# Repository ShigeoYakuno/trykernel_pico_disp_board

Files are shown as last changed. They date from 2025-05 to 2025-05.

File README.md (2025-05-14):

# trykernel_pico_disp_board

### 液晶のON/OFF回路
- MOSFETを使います
- 秋月で売っている30円のBSS138 Panjit製を使います
- Vthが1.5Vと使いやすいです
- 300mAしか引けませんが、液晶は100mA程度なので問題ないでしょう
- NチャネルのMOSFETです
- 


### MOSFETの基本回路通りに構成



- 基本回路どおりに設計します
- マイコン側に電流が流れる可能性があるので、直接受けず、抵抗を介します
- オープンドレイン接続を想定し、ゲートはプルダウンしておきます













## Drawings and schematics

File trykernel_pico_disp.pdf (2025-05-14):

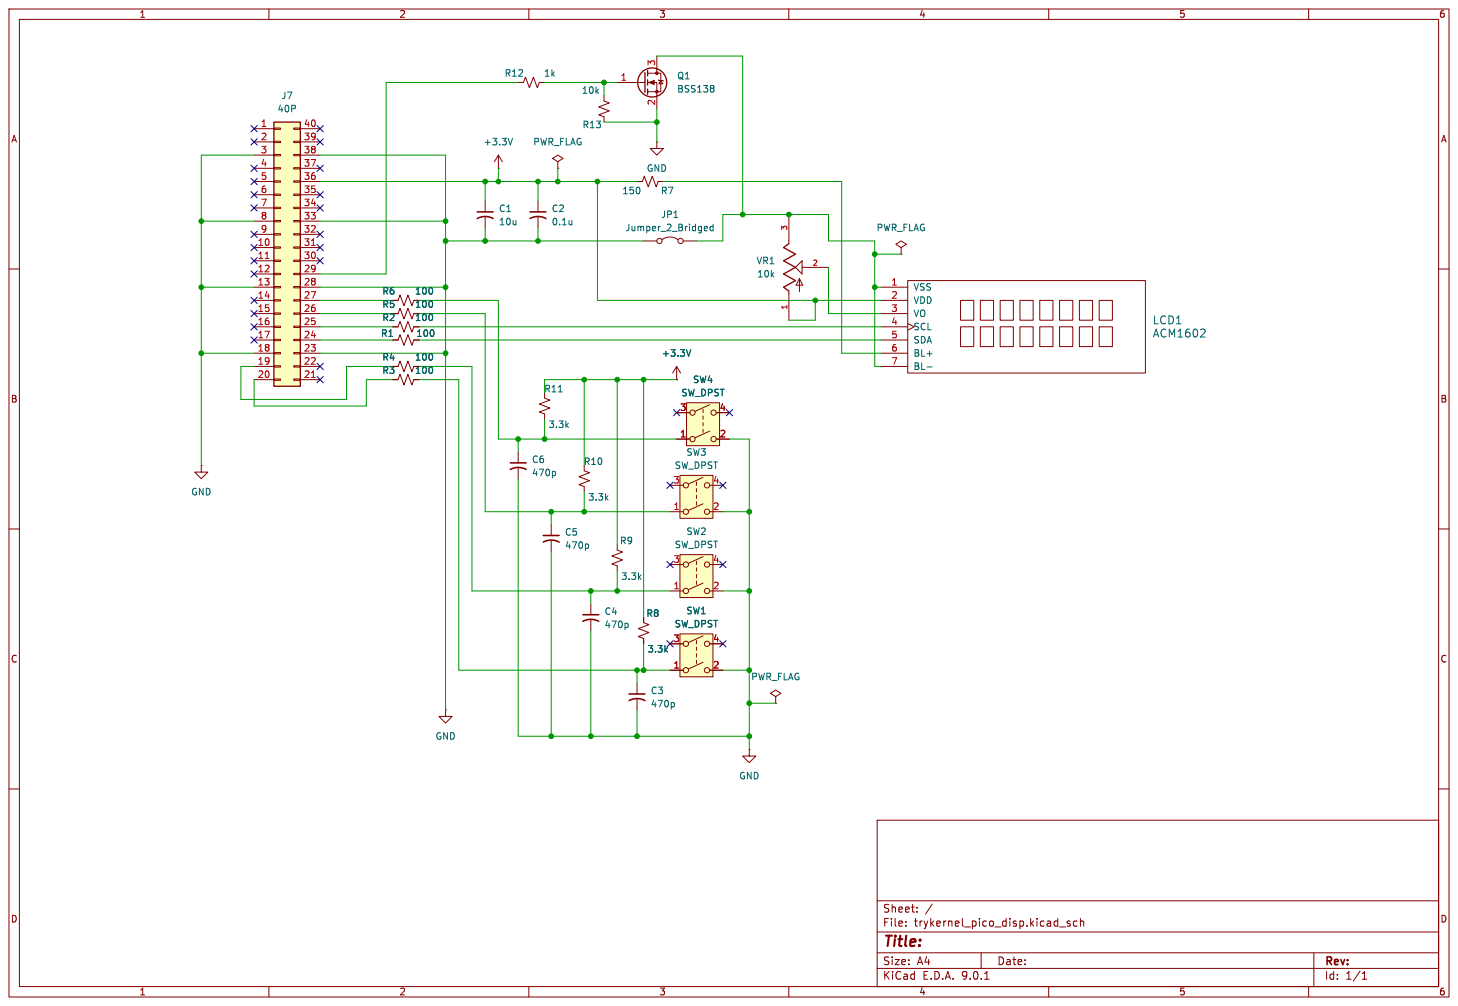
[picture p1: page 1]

Id: 1/1 Title: File: trykernel_pico_disp.kicad_sch Sheet: /

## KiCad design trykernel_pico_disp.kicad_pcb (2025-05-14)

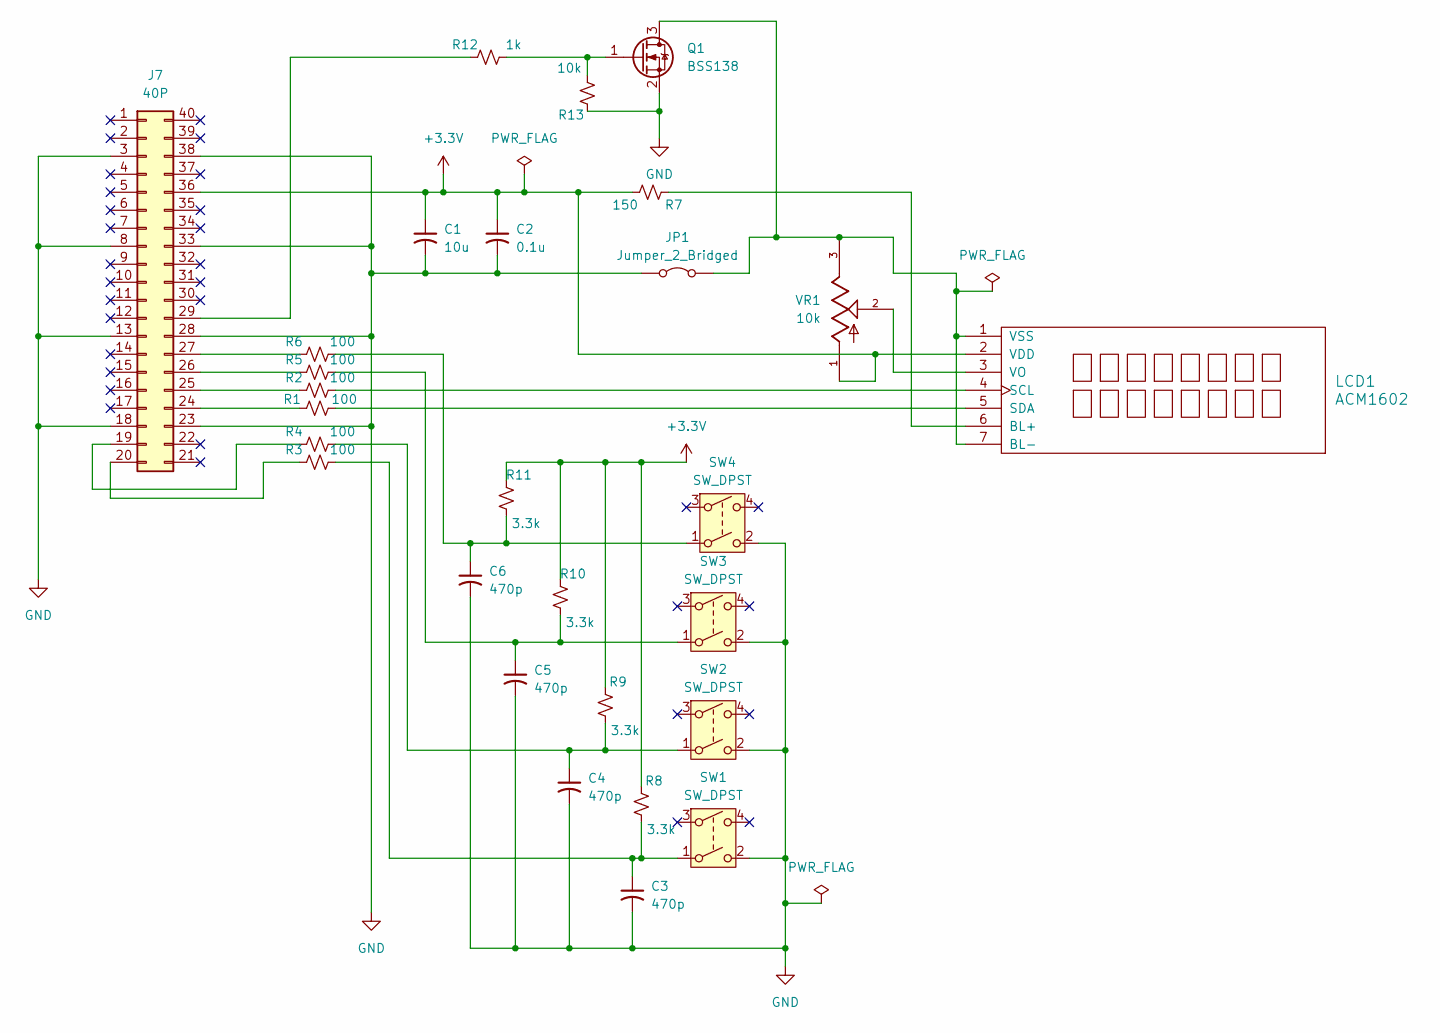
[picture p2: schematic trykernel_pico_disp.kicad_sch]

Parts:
C1: 10u; C_0603_1608Metric_Pad1.08x0.95mm_HandSolder
C2: 0.1u; C_0603_1608Metric_Pad1.08x0.95mm_HandSolder
C3, C4, C5, C6: 470p; C_0603_1608Metric_Pad1.08x0.95mm_HandSolder
J7: 40P; RPI_Hat_B+
JP1: Jumper_2_Bridged; PinHeader_1x02_P2.54mm_Vertical
LCD1: ACM1602; I2C_LCD-ACM1602NI-FLW-FBW-M01
Q1: BSS138; SOT-23
R1, R2, R3, R4, R5, R6: 100; R_0603_1608Metric_Pad0.98x0.95mm_HandSolder
R7: 150; R_0603_1608Metric_Pad0.98x0.95mm_HandSolder
R8, R9, R10, R11: 3.3k; R_0603_1608Metric_Pad0.98x0.95mm_HandSolder
R12: 1k; R_0603_1608Metric_Pad0.98x0.95mm_HandSolder
R13: 10k; R_0603_1608Metric_Pad0.98x0.95mm_HandSolder
SW1, SW2, SW3, SW4: SW_DPST; SW_TACT-EVQQ2Y03W
VR1: 10k; TRIM_3362P-1-103; PARTREV 08/26/10

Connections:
+3.3V: C1.1, C2.1, J7.36, LCD1.2 (VDD), R7.2, R8.1, R9.1, R10.1, R11.1, VR1.1
GND: C1.2, C2.2, C3.2, C4.2, C5.2, C6.2, J7.3, J7.8, J7.13, J7.18, J7.23, J7.28, J7.33, J7.38, JP1.1 (A), Q1.2 (S), R13.1, SW1.2, SW2.2, SW3.2, SW4.2
unnamed: C3.1, R3.2, R8.2, SW1.1
unnamed: C4.1, R4.2, R9.2, SW2.1
unnamed: C5.1, R5.2, R10.2, SW3.1
unnamed: C6.1, R6.2, R11.2, SW4.1
unnamed: J7.19, R4.1
unnamed: J7.20, R3.1
unnamed: J7.24, R1.1
unnamed: J7.25, R2.1
unnamed: J7.26, R5.1
unnamed: J7.27, R6.1
unnamed: J7.29, R12.1
unnamed: JP1.2 (B), LCD1.1 (VSS), LCD1.7 (BL-), Q1.3 (D), VR1.3
unnamed: LCD1.6 (BL+), R7.1
unnamed: LCD1.4 (SCL), R2.2
unnamed: LCD1.5 (SDA), R1.2
unnamed: LCD1.3 (VO), VR1.2
unnamed: Q1.1 (G), R12.2, R13.2

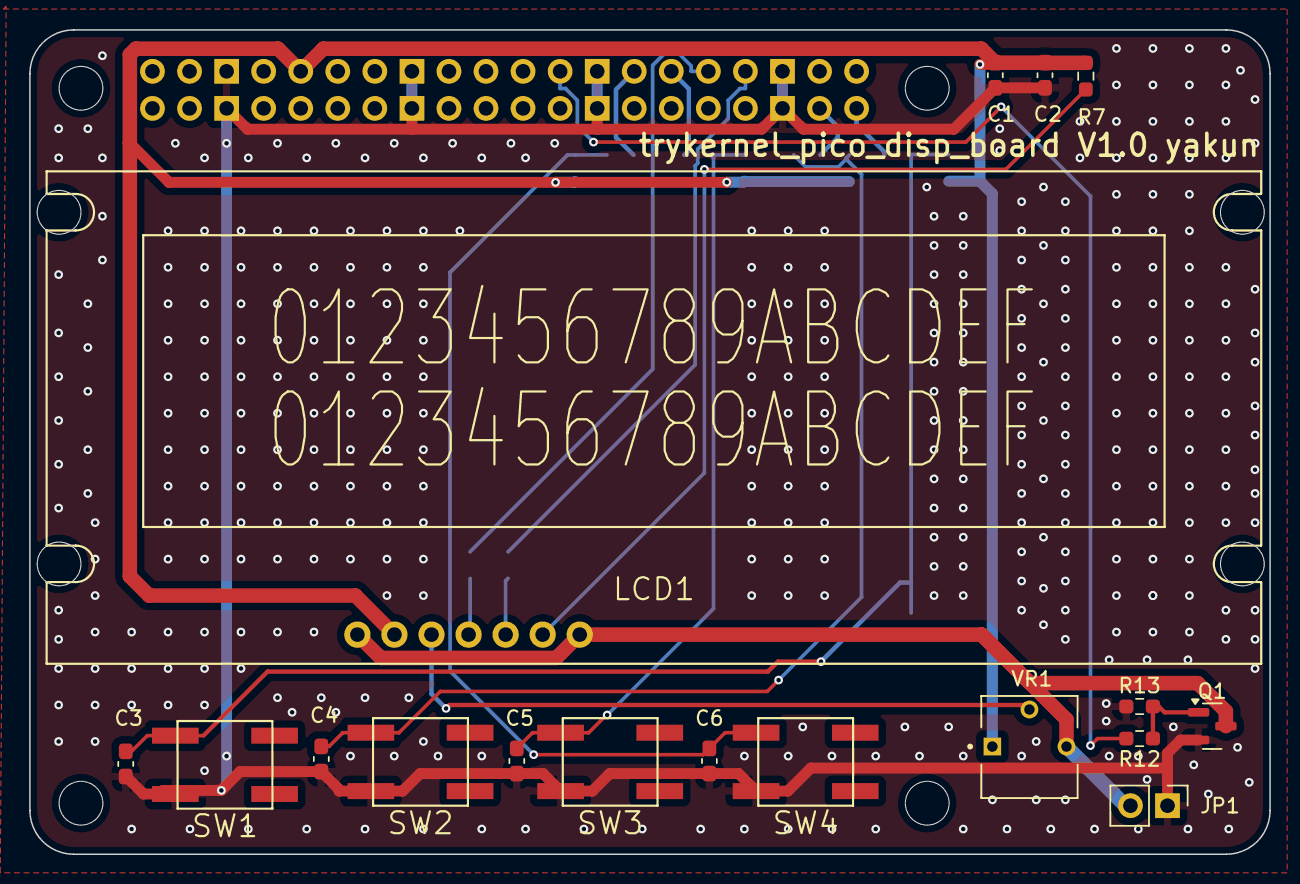
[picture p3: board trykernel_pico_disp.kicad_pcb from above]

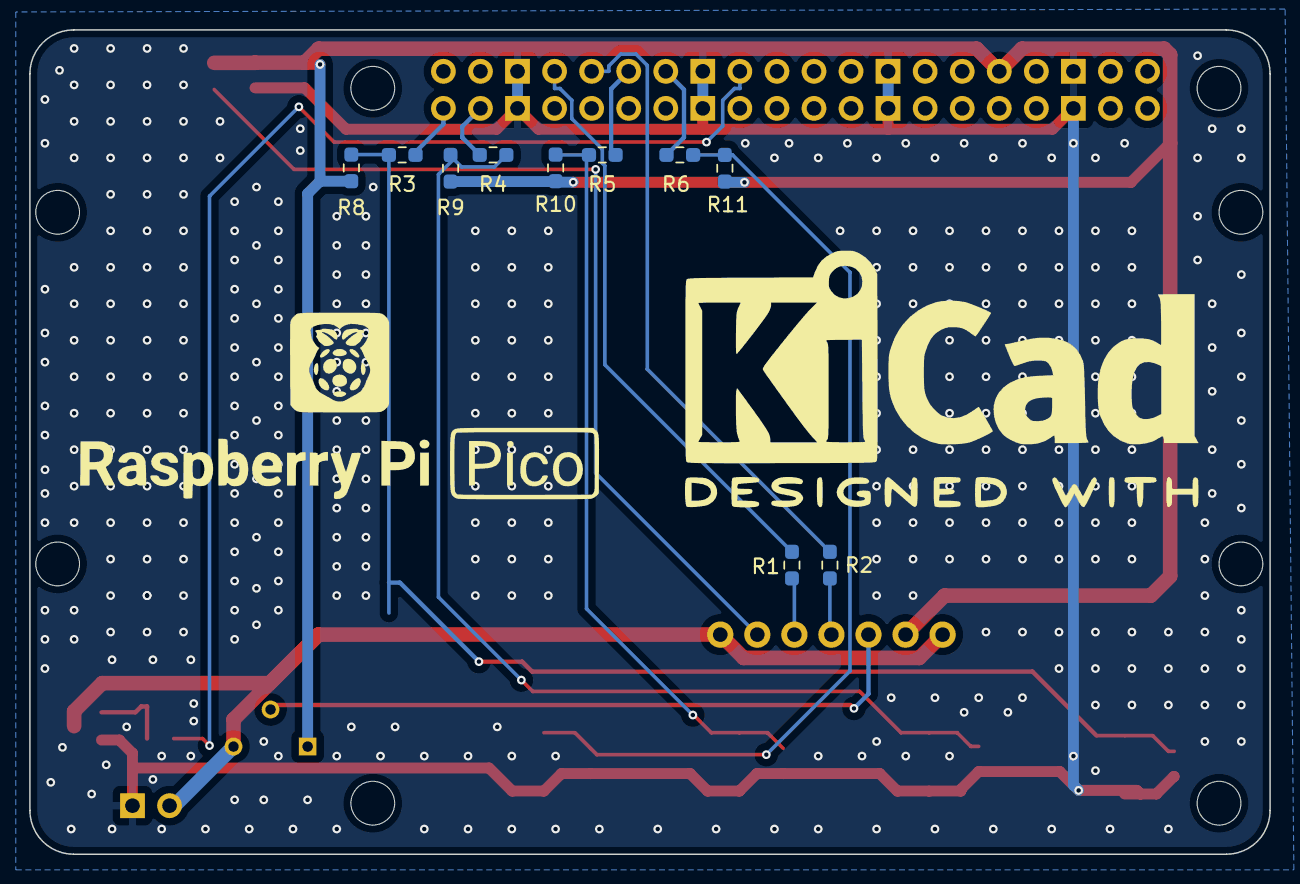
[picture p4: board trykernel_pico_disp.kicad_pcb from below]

Board: 2 copper layers, 85.0 x 56.5 mm, 28 parts (10 on the bottom side), 19 nets.
